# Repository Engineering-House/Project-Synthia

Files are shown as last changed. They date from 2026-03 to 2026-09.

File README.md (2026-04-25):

# Project Synthia
Project Synthia is a digital synthesizer that is designed based upon the Suzuki Omnichord. This repository contains the firmware code for the microcontroller.

## Equipment
The microcontroller used in Project Synthia is a ______.

The programs used are as follows:
- STMCube32MX
- Visual Studio Code
  - STM32CubeIDE for Visual Studio Code (Extension Pack)

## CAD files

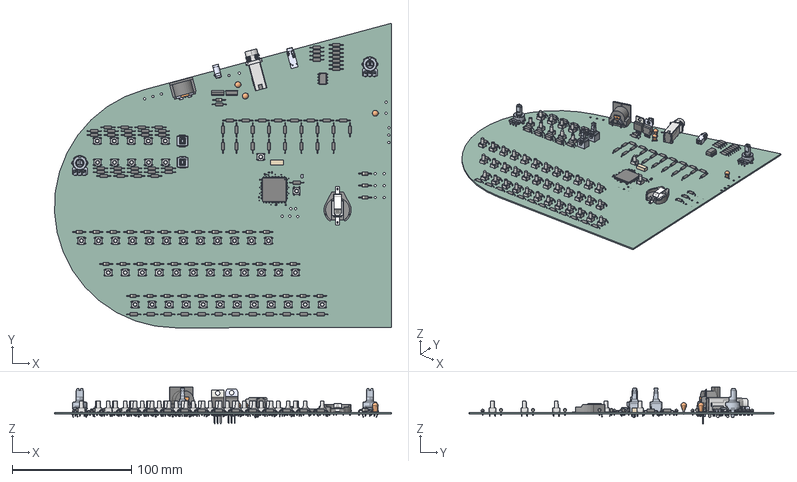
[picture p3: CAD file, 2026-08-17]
synthia/PCB-3D-model-2.step
282.3 x 255.2 x 30.9 mm
STA_CF14_STP x 78
D_DO-41_SOD81_P10.16mm_Horizontal x 40
CAP_CL05_SAM x 15
LQFP144_STM
PVA1EEH31.2NV2 x 2
G-188_MUR x 2
MMBT3904--3DModel-STEP-711646
CAP_CL10_SAM x 2
PJ-007
CCS_CCSTD_0603_L1.75W0.95T0.87B0.35 x 2
CP_Radial_Tantal_D5.0mm_P5.00mm x 3
P120PK x 2
SJ3-35083C-TR
ATS08A-E_CTS
TO-220-3_Vertical
630BT-1
PRT0003-1
630C2-1
630GZ-1
SDS-50J
TLV272IP
LD1117V33
synthia_PCB

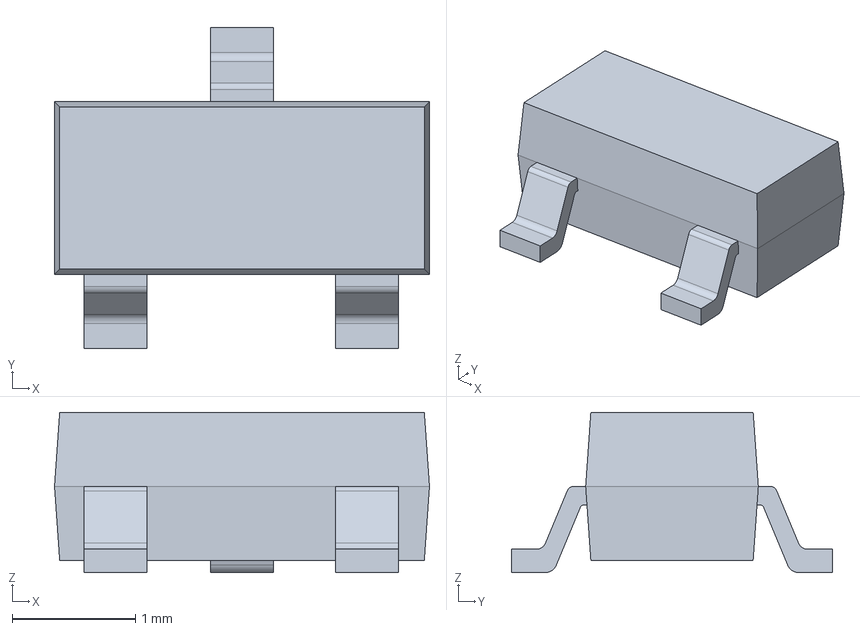
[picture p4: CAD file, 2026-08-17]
synthia/Symbol-and-Footprints/3D_models/sot-23.step
3.04 x 2.60 x 1.30 mm

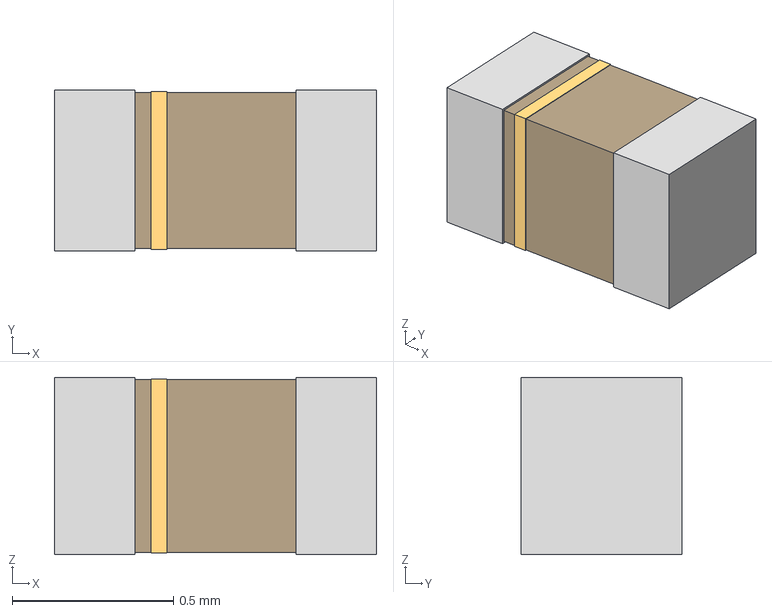
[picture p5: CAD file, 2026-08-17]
synthia/Symbol-and-Footprints/3D_models/CAP_CL05_SAM.step
1.00 x 0.5 x 0.55 mm

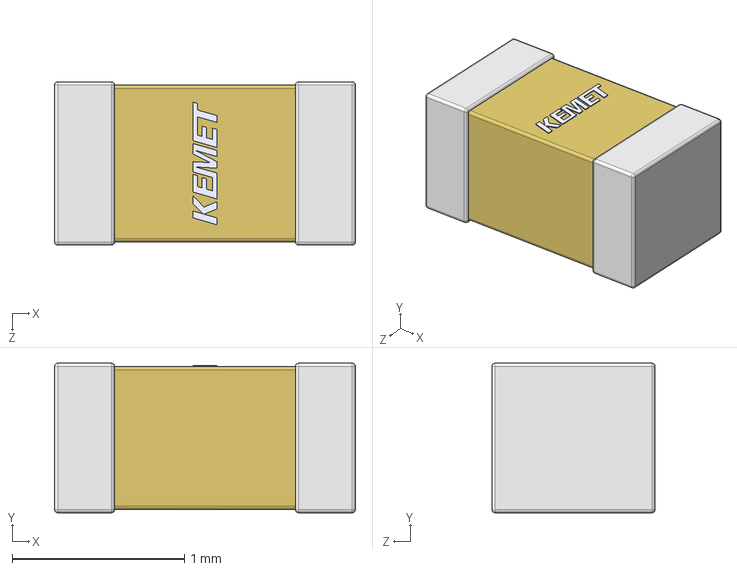
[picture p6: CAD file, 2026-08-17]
synthia/Symbol-and-Footprints/3D_models/CCS_CCSTD_0603_L1.75W0.95T0.87B0.35.step
1.75 x 0.87 x 0.95 mm

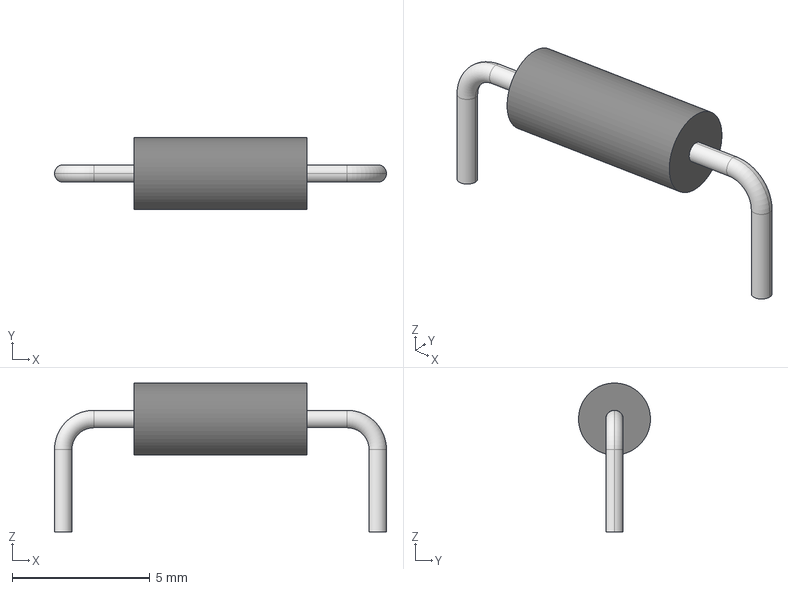
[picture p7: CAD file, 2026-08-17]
synthia/Symbol-and-Footprints/3D_models/STA_CF14_STP.step
12.1 x 2.61 x 5.41 mm

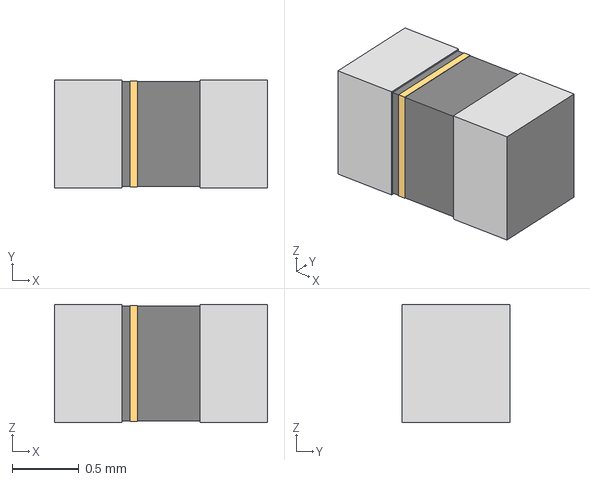
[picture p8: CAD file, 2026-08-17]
synthia/Symbol-and-Footprints/3D_models/G-188_MUR.step
1.60 x 0.812 x 0.889 mm

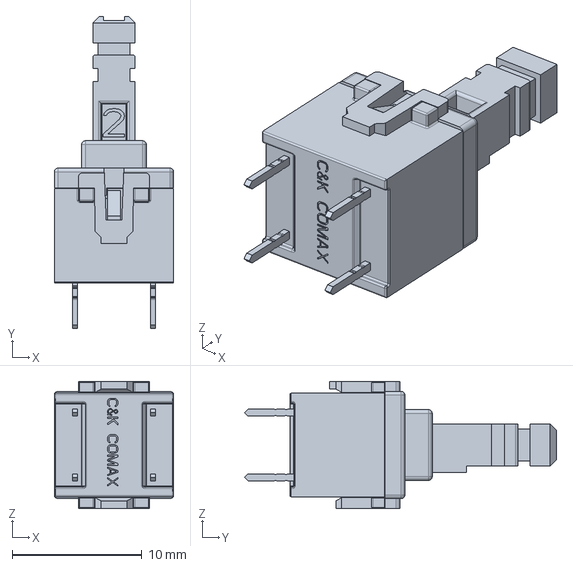
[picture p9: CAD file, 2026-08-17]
synthia/Symbol-and-Footprints/3D_models/PVA1EEH31.2NV2.step
9.20 x 24.0 x 9.80 mm

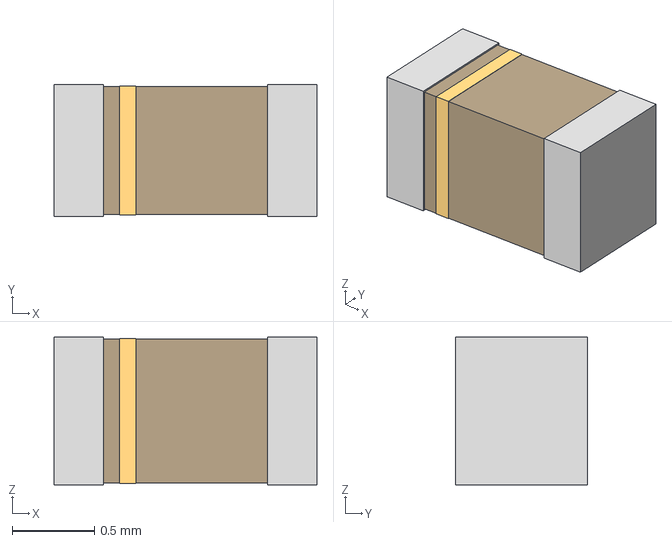
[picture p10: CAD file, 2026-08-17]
synthia/Symbol-and-Footprints/3D_models/CAP_CL10_SAM.step
1.60 x 0.8 x 0.9 mm

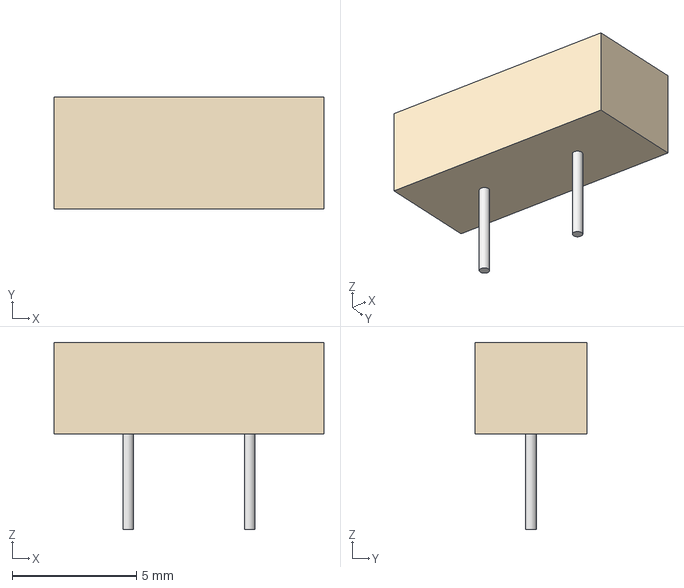
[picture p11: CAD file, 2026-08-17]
synthia/Symbol-and-Footprints/3D_models/ATS08A-E_CTS.step
10.8 x 4.50 x 7.52 mm

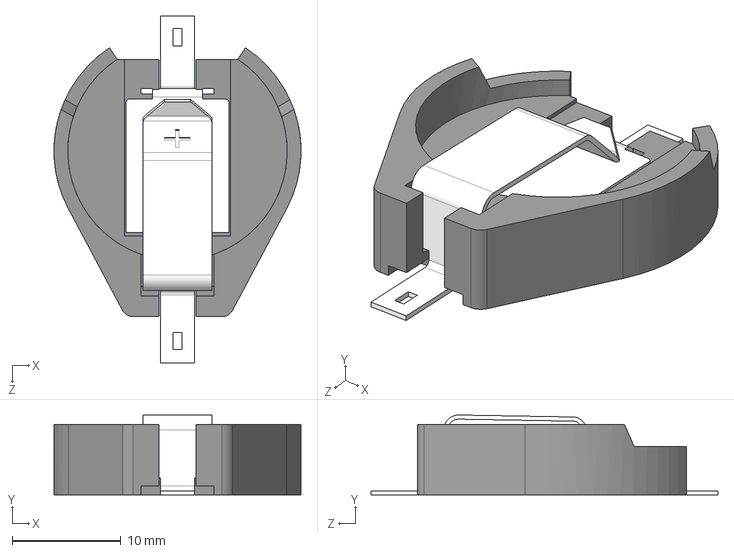
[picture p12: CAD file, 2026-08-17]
synthia/Symbol-and-Footprints/3D_models/1063.step
22.7 x 7.37 x 31.9 mm

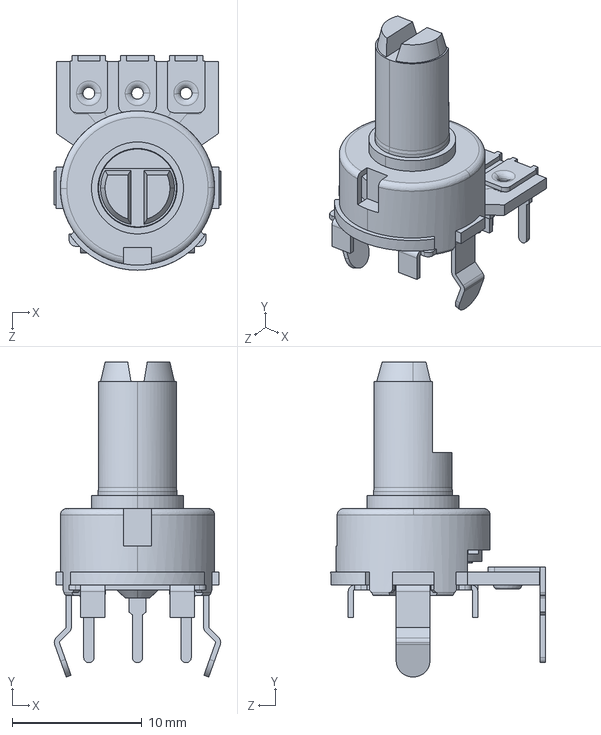
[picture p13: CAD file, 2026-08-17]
synthia/Symbol-and-Footprints/3D_models/P120PK.step
12.8 x 24.3 x 16.6 mm

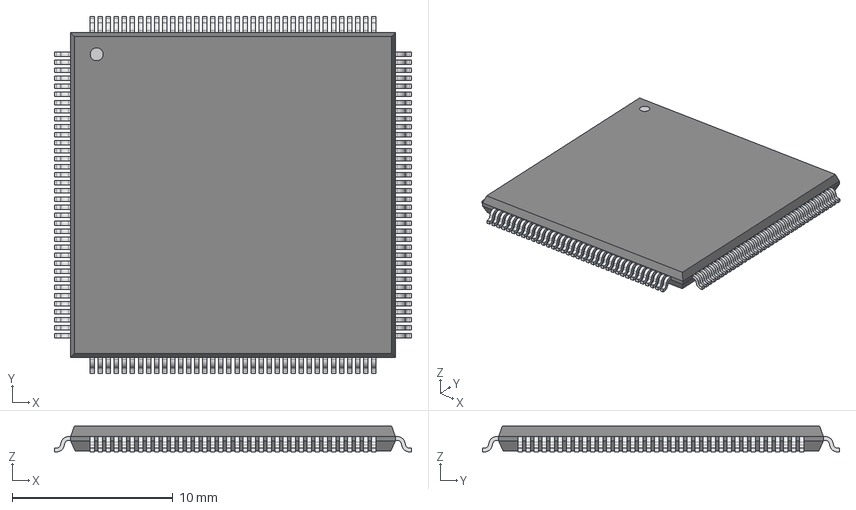
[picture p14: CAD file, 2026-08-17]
synthia/Symbol-and-Footprints/3D_models/LQFP144_STM.step
22.2 x 22.2 x 1.60 mm

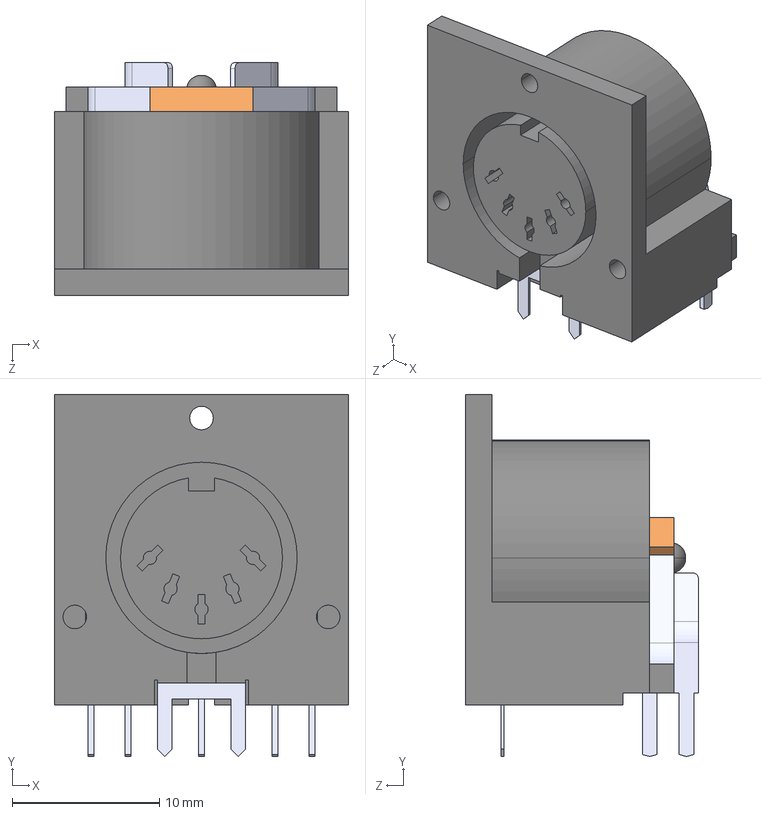
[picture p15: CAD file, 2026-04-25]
synthia/Symbol-and-Footprints/3D_models/SDS-50J.step
20.0 x 24.6 x 15.8 mm

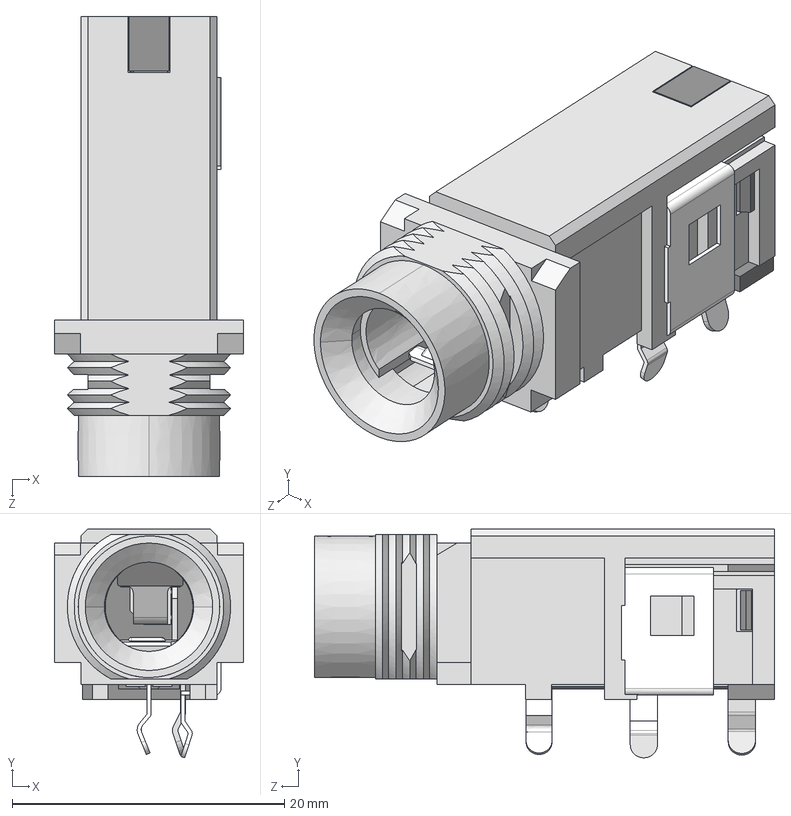
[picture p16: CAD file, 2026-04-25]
synthia/Symbol-and-Footprints/3D_models/MJ-63022B.step
13.9 x 16.8 x 33.8 mm
630BT-1
PRT0003-1
630C2-1
630GZ-1

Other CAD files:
synthia/PCB-3D-model.step
synthia/Symbol-and-Footprints/3D_models/BAS70-05.STEP
synthia/Symbol-and-Footprints/3D_models/SJ3-35083C-TR.step
synthia/Symbol-and-Footprints/3D_models/PJ-007.step
synthia/Symbol-and-Footprints/3D_models/L78M05CV.step
synthia/Symbol-and-Footprints/3D_models/LD1117V33.step
synthia/Symbol-and-Footprints/3D_models/TL1105BF160Q.step
synthia/Symbol-and-Footprints/3D_models/TLV272IP.step

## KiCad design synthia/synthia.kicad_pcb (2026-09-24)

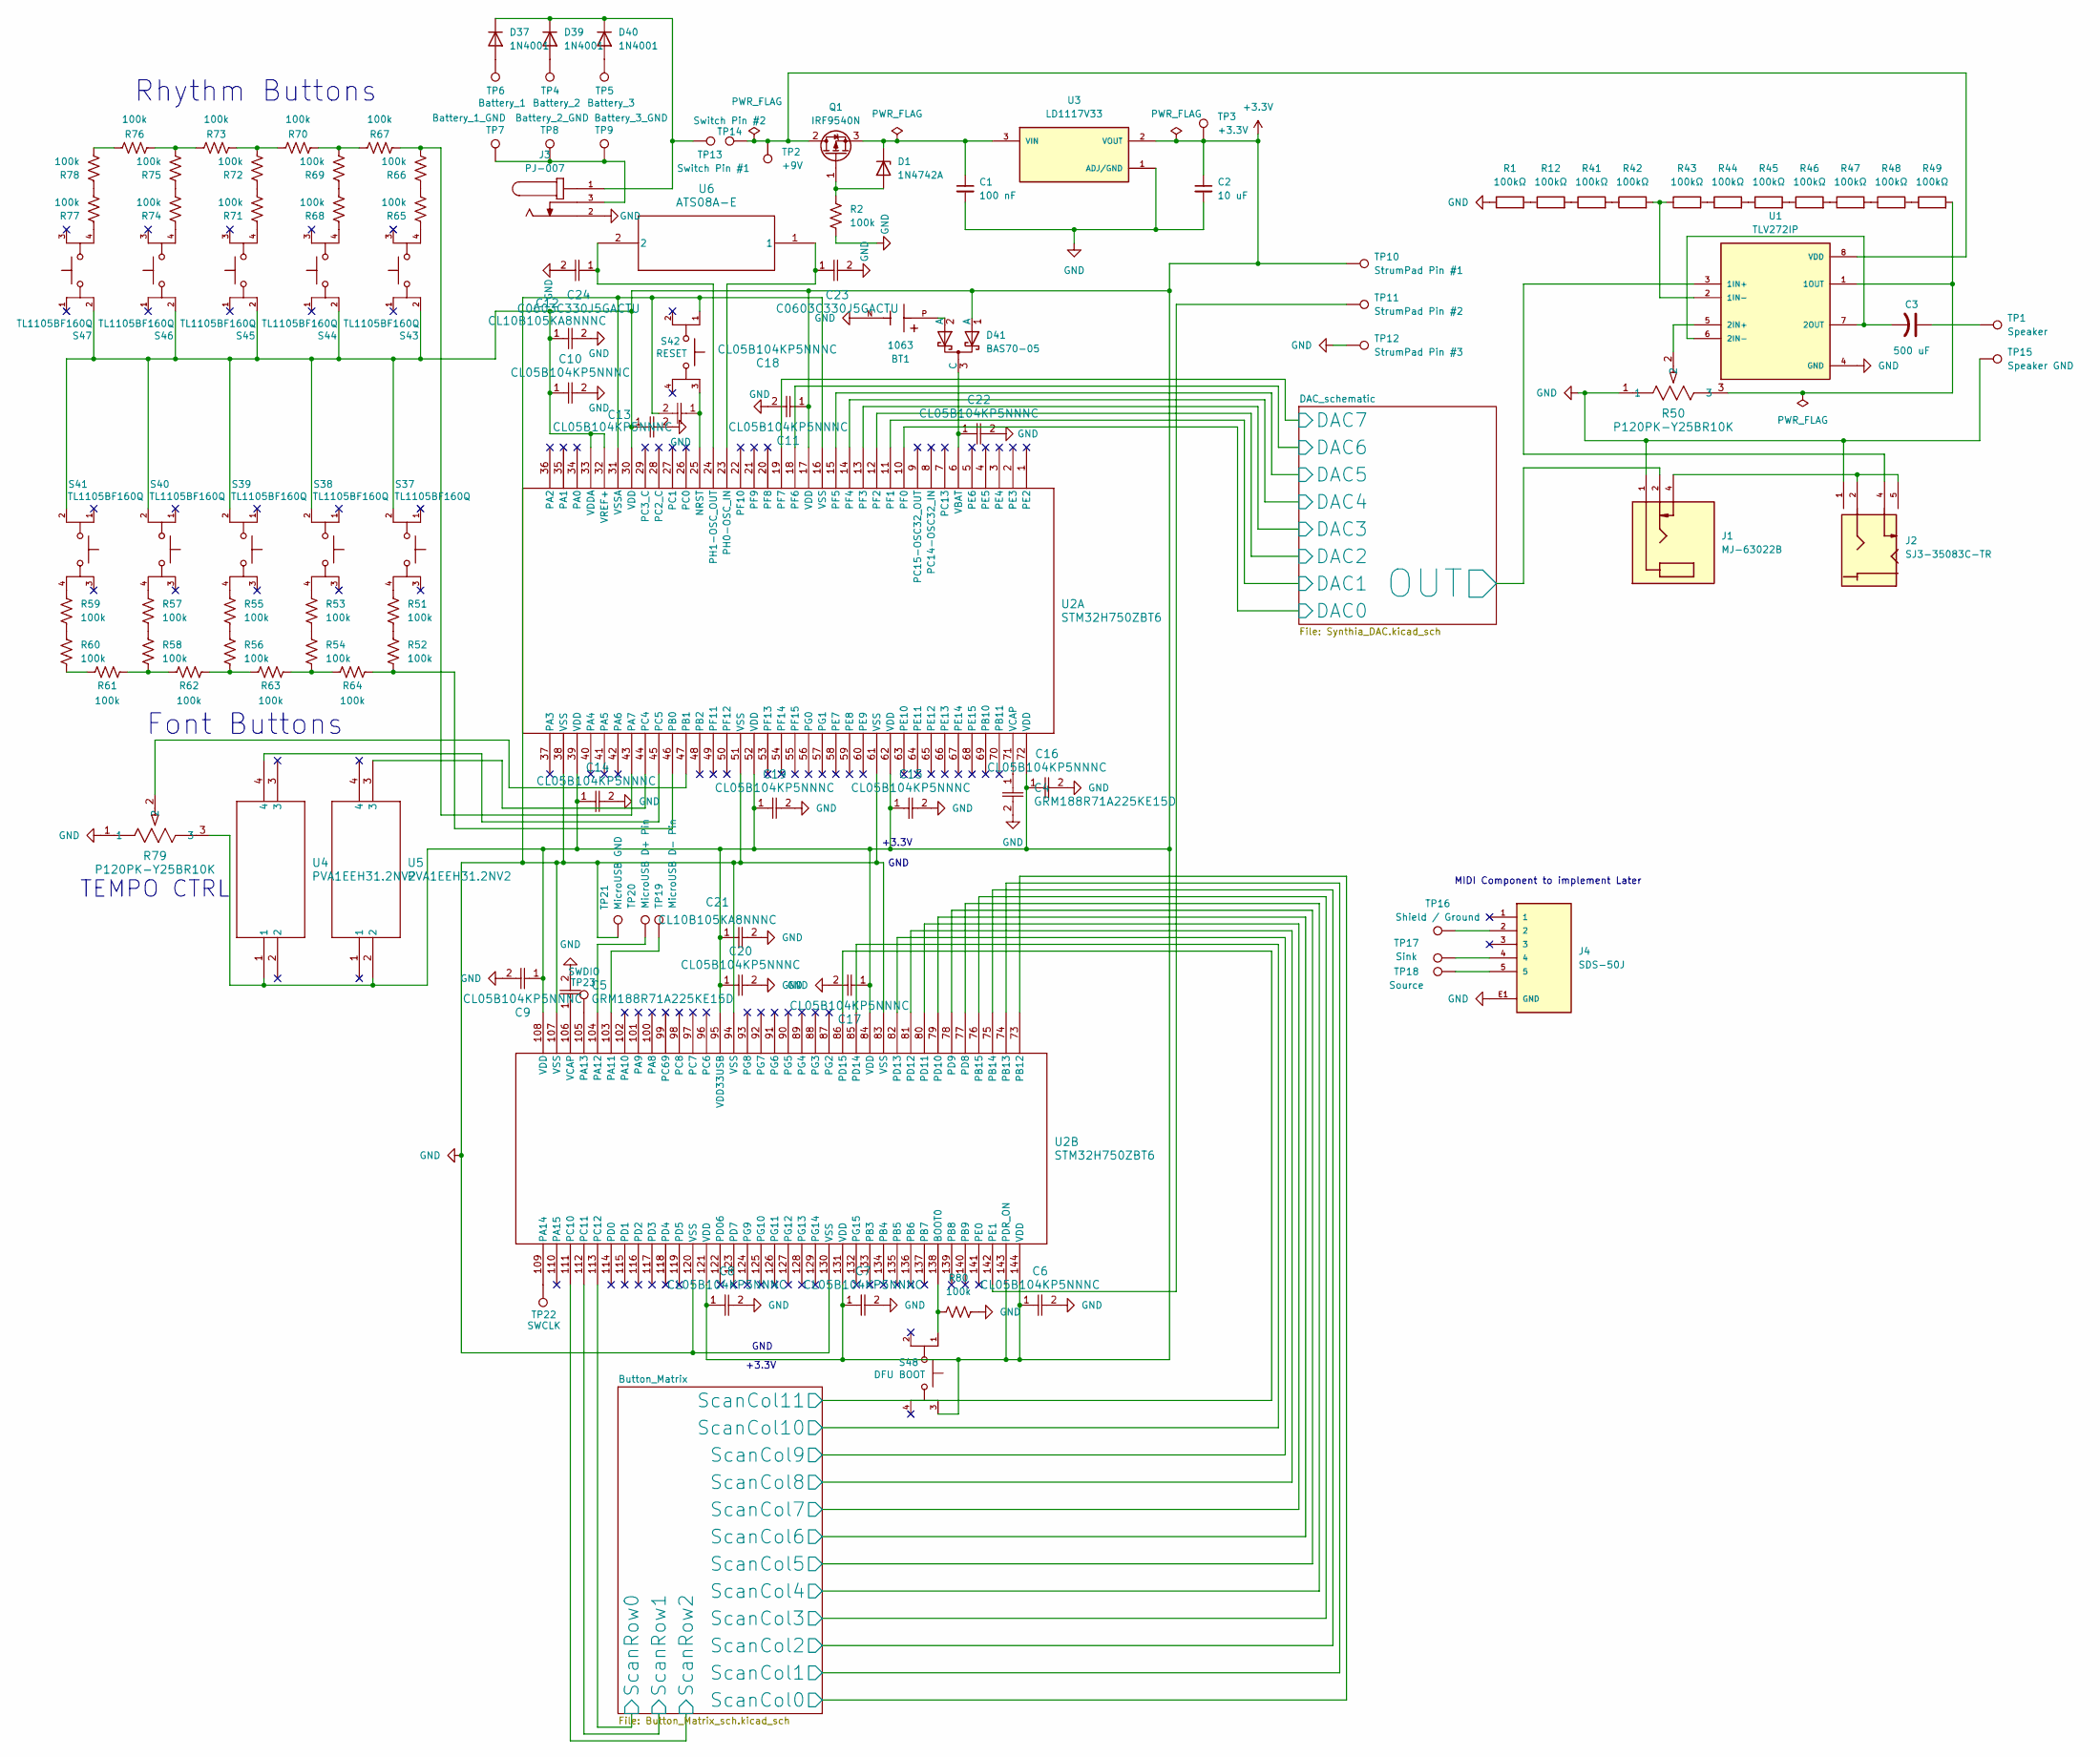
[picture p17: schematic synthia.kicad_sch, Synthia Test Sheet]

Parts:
BT1: 1063; BAT_1063; PARTREV F
C1: 100 nF; CP_Radial_Tantal_D5.0mm_P5.00mm
C2: 10 uF; CP_Radial_Tantal_D5.0mm_P5.00mm
C3: 500 uF; CP_Radial_Tantal_D5.0mm_P5.00mm
C4, C5: GRM188R71A225KE15D; G-188_MUR
C6, C7, C8, C9, C10, C11, C13, C14, C15, C16, C17, C18, C19, C20, C22: CL05B104KP5NNNC; CAP_CL05_SAM-L
C12, C21: CL10B105KA8NNNC; CAP_CL10_SAM-L
C23, C24: C0603C330J5GACTU; CAPC17595_87N_KEM-L
D1: 1N4742A; D_DO-41_SOD81_P10.16mm_Horizontal
D37, D39, D40: 1N4001; D_DO-41_SOD81_P10.16mm_Horizontal
D41: BAS70-05; P200_SOT-23
J1: MJ-63022B; CUI_MJ-63022B; PARTREV 1.0
J2: SJ3-35083C-TR; SAMESKY_SJ3-35083C-TR; PARTREV 1.01
J3: PJ-007; SAMESKY_PJ-007; PARTREV 1.07
J4: SDS-50J; CUI_SDS-50J; PARTREV 1.06/02-13-2020
Q1: IRF9540N; TO-220-3_Vertical
R1, R12, R41, R42, R43, R44, R45, R46, R47, R48, R49: 100kΩ; STA_CF14_STP
R2, R51, R52, R53, R54, R55, R56, R57, R58, R59, R60, R61, R62, R63, R64, R65, R66, R67, R68, R69, R70, R71, R72, R73, R74, R75, R76, R77, R78, R80: 100k; STA_CF14_STP
R50, R79: P120PK-Y25BR10K; POT_P120PK-x25_TTE
S37, S38, S39, S40, S41, S43, S44, S45, S46, S47: TL1105BF160Q; SW_TL1105BF160Q; PARTREV A
S42: RESET; SW_TL1105BF160Q; PARTREV A
S48: DFU BOOT; SW_TL1105BF160Q; PARTREV A
TP1: Speaker; TestPoint_Plated_Hole_D2.0mm
TP2: +9V; TestPoint_Pad_2.0x2.0mm
TP3: +3.3V; TestPoint_Pad_2.0x2.0mm
TP4: Battery_2; TestPoint_Plated_Hole_D2.0mm
TP5: Battery_3; TestPoint_Plated_Hole_D2.0mm
TP6: Battery_1; TestPoint_Plated_Hole_D2.0mm
TP7: Battery_1_GND; TestPoint_Plated_Hole_D2.0mm
TP8: Battery_2_GND; TestPoint_Plated_Hole_D2.0mm
TP9: Battery_3_GND; TestPoint_Plated_Hole_D2.0mm
TP10: StrumPad Pin #1; TestPoint_Plated_Hole_D2.0mm
TP11: StrumPad Pin #2; TestPoint_Plated_Hole_D2.0mm
TP12: StrumPad Pin #3; TestPoint_Plated_Hole_D2.0mm
TP13: Switch Pin #1; TestPoint_Plated_Hole_D2.0mm
TP14: Switch Pin #2; TestPoint_Plated_Hole_D2.0mm
TP15: Speaker GND; TestPoint_Plated_Hole_D2.0mm
TP16: Shield / Ground; TestPoint_Plated_Hole_D2.0mm
TP17: Sink; TestPoint_Plated_Hole_D2.0mm
TP18: Source; TestPoint_Plated_Hole_D2.0mm
TP19: MicroUSB D- Pin; TestPoint_Plated_Hole_D2.0mm
TP20: MicroUSB D+ Pin; TestPoint_Plated_Hole_D2.0mm
TP21: MicroUSB GND; TestPoint_Plated_Hole_D2.0mm
TP22: SWCLK; TestPoint_Plated_Hole_D2.0mm
TP23: SWDIO; TestPoint_Plated_Hole_D2.0mm
U1: TLV272IP; DIP794W45P254L959H508Q8; PARTREV E
U2: STM32H750ZBT6; LQFP144_STM
U3: LD1117V33; TO255P1020X450X1968-3; PARTREV 37
U4, U5: PVA1EEH31.2NV2; SWITCH_H31.2NV2
U6: ATS08A-E; ATS08A-E_CTS

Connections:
+3.3V: C2.1, C6.1, C7.1, C8.1, C9.1, C10.1, C11.1, C12.1, C13.1, C14.1, C15.1, C16.1, C17.1, C19.1, C20.1, C21.1, D41.1 (A), R79.3, S37.2, S38.2, S39.2, S40.2, S41.2, S43.2, S44.2, S45.2, S46.2, S47.2, S48.3, TP3.1 (1_1), TP10.1 (1_1), U2.17 (VDD), U2.30 (VDD), U2.32 (VREF+), U2.33 (VDDA), U2.39 (VDD), U2.52 (VDD), U2.62 (VDD), U2.72 (VDD), U2.84 (VDD), U2.95 (VDD33USB), U2.108 (VDD), U2.121 (VDD), U2.131 (VDD), U2.143 (PDR_ON), U2.144 (VDD), U3.2 (VOUT), U4.1, U5.2
/Button_Matrix/ScanCol0: U2.73 (PB12); also elsewhere on the board
/Button_Matrix/ScanCol1: U2.74 (PB13); also elsewhere on the board
/Button_Matrix/ScanCol2: U2.75 (PB14); also elsewhere on the board
/Button_Matrix/ScanCol3: U2.76 (PB15); also elsewhere on the board
/Button_Matrix/ScanCol4: U2.77 (PD8); also elsewhere on the board
/Button_Matrix/ScanCol5: U2.78 (PD9); also elsewhere on the board
/Button_Matrix/ScanCol6: U2.79 (PD10); also elsewhere on the board
/Button_Matrix/ScanCol7: U2.80 (PD11); also elsewhere on the board
/Button_Matrix/ScanCol8: U2.81 (PD12); also elsewhere on the board
/Button_Matrix/ScanCol9: U2.82 (PD13); also elsewhere on the board
/Button_Matrix/ScanCol10: U2.85 (PD14); also elsewhere on the board
/Button_Matrix/ScanCol11: U2.86 (PD15); also elsewhere on the board
/Button_Matrix/ScanRow0: U2.113 (PC12); also elsewhere on the board
/Button_Matrix/ScanRow1: U2.112 (PC11); also elsewhere on the board
/Button_Matrix/ScanRow2: U2.111 (PC10); also elsewhere on the board
/DAC_schematic/DAC0: U2.10 (PF0); also elsewhere on the board
/DAC_schematic/DAC1: U2.11 (PF1); also elsewhere on the board
/DAC_schematic/DAC2: U2.12 (PF2); also elsewhere on the board
/DAC_schematic/DAC3: U2.13 (PF3); also elsewhere on the board
/DAC_schematic/DAC4: U2.14 (PF4); also elsewhere on the board
/DAC_schematic/DAC5: U2.15 (PF5); also elsewhere on the board
/DAC_schematic/DAC6: U2.18 (PF6); also elsewhere on the board
/DAC_schematic/DAC7: U2.19 (PF7); also elsewhere on the board
/DAC_schematic/OUT: J1.2; also elsewhere on the board
GND: BT1.N, C1.2, C2.2, C4.2, C5.2, C6.2, C7.2, C8.2, C9.2, C10.2, C11.2, C12.2, C13.2, C14.2, C15.2, C16.2, C17.2, C18.2, C19.2, C20.2, C21.2, C22.2, C23.2, C24.2, J1.1, J2.1, J3.2, J4.E1 (GND), J4.E2 (GND), R1.1, R2.2, R50.1, R79.1, R80.2, S42.1, TP12.1 (1_1), TP15.1 (1_1), TP21.1 (1_1), U1.4 (GND), U2.16 (VSS), U2.31 (VSSA), U2.38 (VSS), U2.51 (VSS), U2.61 (VSS), U2.83 (VSS), U2.94 (VSS), U2.107 (VSS), U2.120 (VSS), U2.130 (VSS), U3.1 (ADJ/GND); also elsewhere on the board
unnamed: BT1.P, D41.2 (A)
unnamed: C3.1, TP1.1 (1_1)
unnamed: D1.2 (A), Q1.1 (G), R2.1
unnamed: C1.1, D1.1 (K), Q1.3 (S), U3.3 (VIN)
unnamed: D37.2 (A), TP6.1 (1_1)
unnamed: D37.1 (K), D39.1 (K), D40.1 (K), J3.1, TP13.1 (1_1)
unnamed: D39.2 (A), TP4.1 (1_1)
unnamed: D40.2 (A), TP5.1 (1_1)
unnamed: C22.1, D41.3 (C), U2.6 (VBAT)
unnamed: J1.4, J2.2, J2.5
unnamed: J3.3, TP7.1 (1_1), TP8.1 (1_1), TP9.1 (1_1)
unnamed: J4.2, TP16.1 (1_1)
unnamed: J4.4, TP17.1 (1_1)
unnamed: J4.5, TP18.1 (1_1)
unnamed: Q1.2 (D), TP2.1 (1_1), TP14.1 (1_1), U1.8 (VDD)
unnamed: R1.2, R12.1
unnamed: R12.2, R41.1
unnamed: R41.2, R42.1
unnamed: R43.2, R44.1
unnamed: R44.2, R45.1
unnamed: R45.2, R46.1
unnamed: R46.2, R47.1
unnamed: R47.2, R48.1
unnamed: R48.2, R49.1
unnamed: R51.1, S37.4
unnamed: R51.2, R52.1
unnamed: R53.1, S38.4
unnamed: R53.2, R54.1
unnamed: R54.2, R63.2, R64.1
unnamed: R55.1, S39.4
unnamed: R55.2, R56.1
unnamed: R56.2, R62.2, R63.1
unnamed: R57.1, S40.4
unnamed: R57.2, R58.1
unnamed: R58.2, R61.2, R62.1
unnamed: R59.1, S41.4
unnamed: R59.2, R60.1
unnamed: R60.2, R61.1
unnamed: R65.1, S43.4
unnamed: R65.2, R66.1
unnamed: R67.2, R69.2, R70.1
unnamed: R68.1, S44.4
unnamed: R68.2, R69.1
unnamed: R70.2, R72.2, R73.1
unnamed: R71.1, S45.4
unnamed: R71.2, R72.1
unnamed: R73.2, R75.2, R76.1
unnamed: R74.1, S46.4
unnamed: R74.2, R75.1
unnamed: R76.2, R78.2
unnamed: R77.1, S47.4
unnamed: R77.2, R78.1
unnamed: J2.4, U1.3 (1IN+)
unnamed: R42.2, R43.1, U1.2 (1IN-)
unnamed: R49.2, R50.3, U1.1 (1OUT)
unnamed: R50.2, U1.5 (2IN+)
unnamed: C3.2, U1.6 (2IN-), U1.7 (2OUT)
unnamed: C18.1, S42.3, U2.25 (NRST)
unnamed: R66.2, R67.1, U2.43 (PA7)
unnamed: R52.2, R64.2, U2.46 (PB0)
unnamed: R79.2, U2.47 (PB1)
unnamed: U2.44 (PC4), U5.3
unnamed: U2.45 (PC5), U4.4
unnamed: C23.1, U2.23 (PH0-OSC_IN), U6.1
unnamed: C24.1, U2.24 (PH1-OSC_OUT), U6.2
unnamed: C4.1, U2.71 (VCAP)
unnamed: R80.1, S48.1, U2.138 (BOOT0)
unnamed: TP19.1 (1_1), U2.103 (PA11)
unnamed: TP20.1 (1_1), U2.104 (PA12)
unnamed: TP23.1 (1_1), U2.105 (PA13)
unnamed: TP22.1 (1_1), U2.109 (PA14)
unnamed: TP11.1 (1_1), U2.142 (PE1)
unnamed: C5.1, U2.106 (VCAP)

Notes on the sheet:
+3.3V
GND
TEMPO CTRL
MIDI Component to implement Later
Font Buttons
Rhythm Buttons

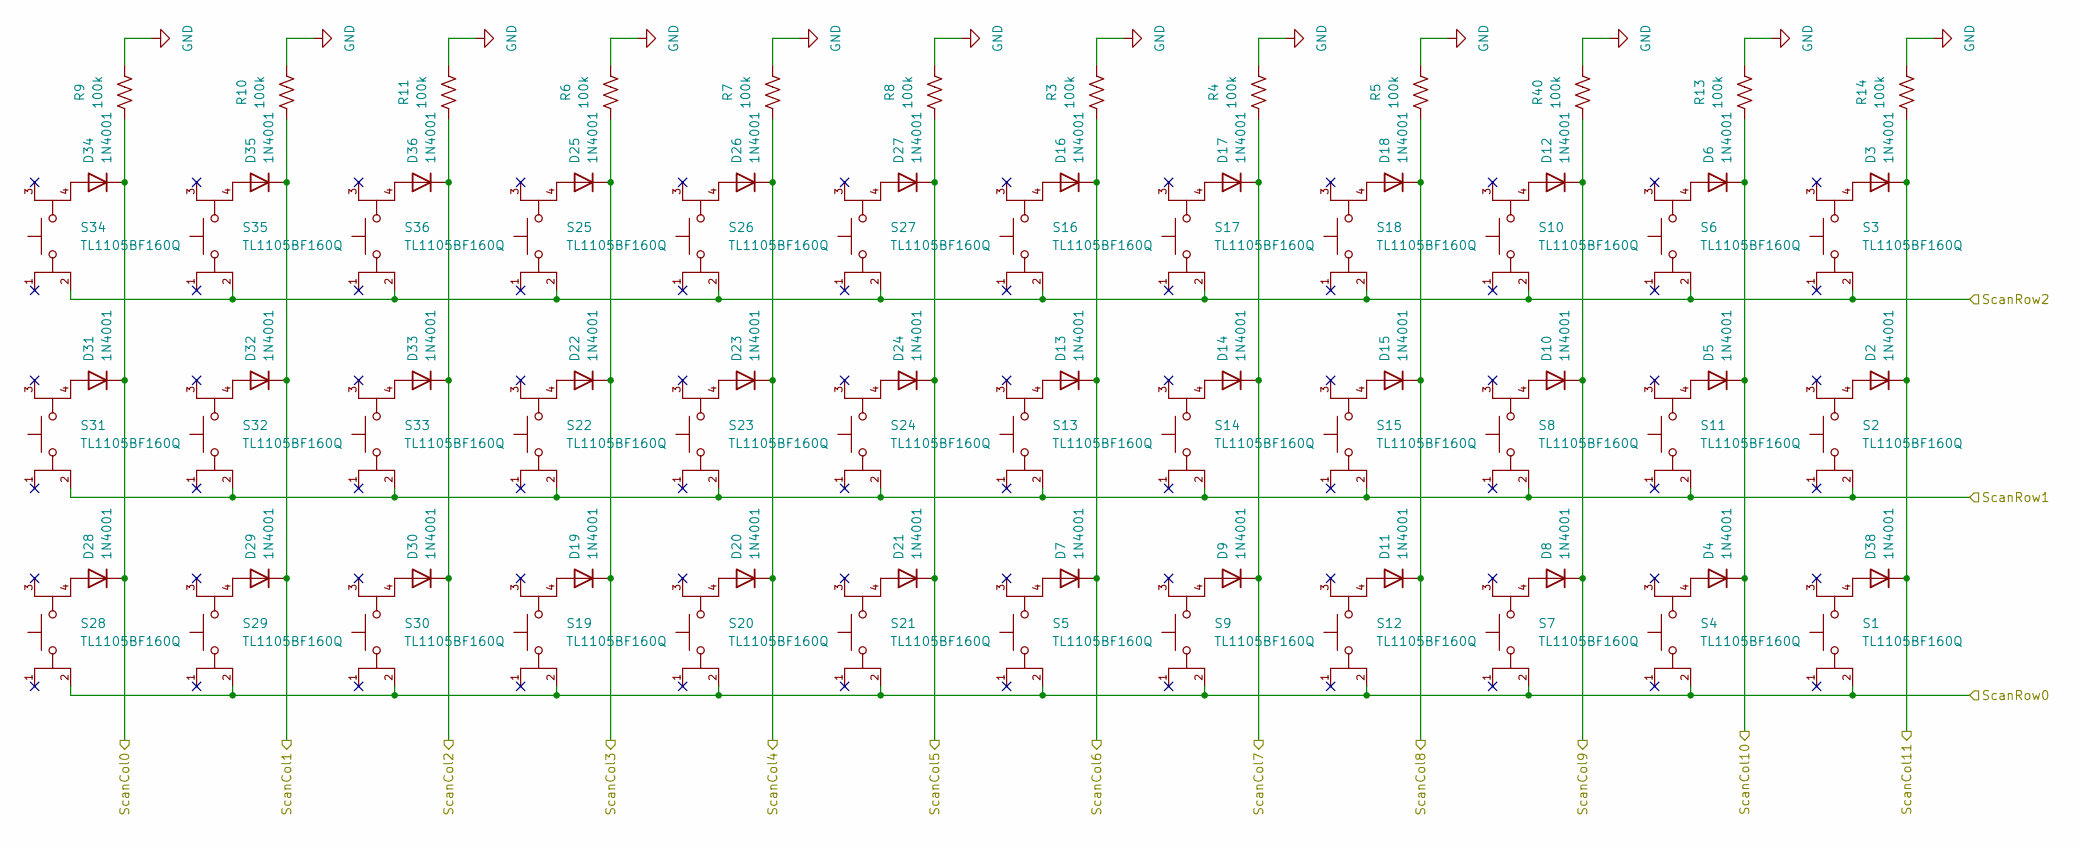
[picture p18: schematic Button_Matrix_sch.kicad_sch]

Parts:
D2, D3, D4, D5, D6, D7, D8, D9, D10, D11, D12, D13, D14, D15, D16, D17, D18, D19, D20, D21, D22, D23, D24, D25, D26, D27, D28, D29, D30, D31, D32, D33, D34, D35, D36, D38: 1N4001; D_DO-41_SOD81_P10.16mm_Horizontal
R3, R4, R5, R6, R7, R8, R9, R10, R11, R13, R14, R40: 100k; STA_CF14_STP
S1, S2, S3, S4, S5, S6, S7, S8, S9, S10, S11, S12, S13, S14, S15, S16, S17, S18, S19, S20, S21, S22, S23, S24, S25, S26, S27, S28, S29, S30, S31, S32, S33, S34, S35, S36: TL1105BF160Q; SW_TL1105BF160Q; PARTREV A

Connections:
/Button_Matrix/ScanCol0: D28.1 (K), D31.1 (K), D34.1 (K), R9.1; also elsewhere on the board
/Button_Matrix/ScanCol1: D29.1 (K), D32.1 (K), D35.1 (K), R10.1; also elsewhere on the board
/Button_Matrix/ScanCol2: D30.1 (K), D33.1 (K), D36.1 (K), R11.1; also elsewhere on the board
/Button_Matrix/ScanCol3: D19.1 (K), D22.1 (K), D25.1 (K), R6.1; also elsewhere on the board
/Button_Matrix/ScanCol4: D20.1 (K), D23.1 (K), D26.1 (K), R7.1; also elsewhere on the board
/Button_Matrix/ScanCol5: D21.1 (K), D24.1 (K), D27.1 (K), R8.1; also elsewhere on the board
/Button_Matrix/ScanCol6: D7.1 (K), D13.1 (K), D16.1 (K), R3.1; also elsewhere on the board
/Button_Matrix/ScanCol7: D9.1 (K), D14.1 (K), D17.1 (K), R4.1; also elsewhere on the board
/Button_Matrix/ScanCol8: D11.1 (K), D15.1 (K), D18.1 (K), R5.1; also elsewhere on the board
/Button_Matrix/ScanCol9: D8.1 (K), D10.1 (K), D12.1 (K), R40.1; also elsewhere on the board
/Button_Matrix/ScanCol10: D4.1 (K), D5.1 (K), D6.1 (K), R13.1; also elsewhere on the board
/Button_Matrix/ScanCol11: D2.1 (K), D3.1 (K), D38.1 (K), R14.1; also elsewhere on the board
/Button_Matrix/ScanRow0: S1.2, S4.2, S5.2, S7.2, S9.2, S12.2, S19.2, S20.2, S21.2, S28.2, S29.2, S30.2; also elsewhere on the board
/Button_Matrix/ScanRow1: S2.2, S8.2, S11.2, S13.2, S14.2, S15.2, S22.2, S23.2, S24.2, S31.2, S32.2, S33.2; also elsewhere on the board
/Button_Matrix/ScanRow2: S3.2, S6.2, S10.2, S16.2, S17.2, S18.2, S25.2, S26.2, S27.2, S34.2, S35.2, S36.2; also elsewhere on the board
GND: R3.2, R4.2, R5.2, R6.2, R7.2, R8.2, R9.2, R10.2, R11.2, R13.2, R14.2, R40.2; also elsewhere on the board
unnamed: D2.2 (A), S2.4
unnamed: D3.2 (A), S3.4
unnamed: D4.2 (A), S4.4
unnamed: D5.2 (A), S11.4
unnamed: D6.2 (A), S6.4
unnamed: D7.2 (A), S5.4
unnamed: D8.2 (A), S7.4
unnamed: D9.2 (A), S9.4
unnamed: D10.2 (A), S8.4
unnamed: D11.2 (A), S12.4
unnamed: D12.2 (A), S10.4
unnamed: D13.2 (A), S13.4
unnamed: D14.2 (A), S14.4
unnamed: D15.2 (A), S15.4
unnamed: D16.2 (A), S16.4
unnamed: D17.2 (A), S17.4
unnamed: D18.2 (A), S18.4
unnamed: D19.2 (A), S19.4
unnamed: D20.2 (A), S20.4
unnamed: D21.2 (A), S21.4
unnamed: D22.2 (A), S22.4
unnamed: D23.2 (A), S23.4
unnamed: D24.2 (A), S24.4
unnamed: D25.2 (A), S25.4
unnamed: D26.2 (A), S26.4
unnamed: D27.2 (A), S27.4
unnamed: D28.2 (A), S28.4
unnamed: D29.2 (A), S29.4
unnamed: D30.2 (A), S30.4
unnamed: D31.2 (A), S31.4
unnamed: D32.2 (A), S32.4
unnamed: D33.2 (A), S33.4
unnamed: D34.2 (A), S34.4
unnamed: D35.2 (A), S35.4
unnamed: D36.2 (A), S36.4
unnamed: D38.2 (A), S1.4

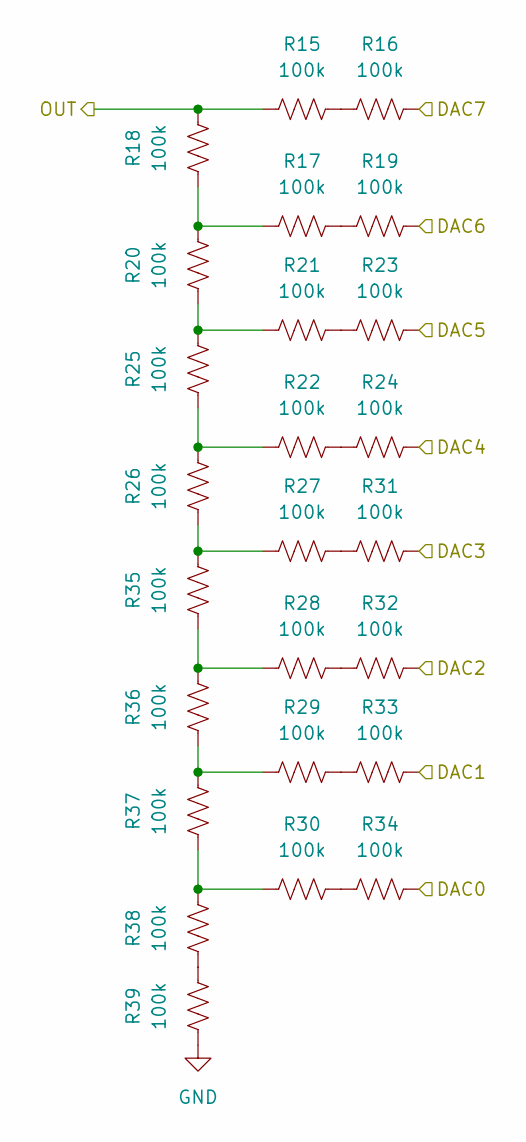
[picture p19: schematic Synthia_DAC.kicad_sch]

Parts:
R15, R16, R17, R18, R19, R20, R21, R22, R23, R24, R25, R26, R27, R28, R29, R30, R31, R32, R33, R34, R35, R36, R37, R38, R39: 100k; STA_CF14_STP

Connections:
/DAC_schematic/DAC0: R34.2; also elsewhere on the board
/DAC_schematic/DAC1: R33.2; also elsewhere on the board
/DAC_schematic/DAC2: R32.2; also elsewhere on the board
/DAC_schematic/DAC3: R31.2; also elsewhere on the board
/DAC_schematic/DAC4: R24.2; also elsewhere on the board
/DAC_schematic/DAC5: R23.2; also elsewhere on the board
/DAC_schematic/DAC6: R19.2; also elsewhere on the board
/DAC_schematic/DAC7: R16.2; also elsewhere on the board
/DAC_schematic/OUT: R15.1, R18.2; also elsewhere on the board
GND: R39.1; also elsewhere on the board
unnamed: R15.2, R16.1
unnamed: R17.1, R18.1, R20.2
unnamed: R17.2, R19.1
unnamed: R20.1, R21.1, R25.2
unnamed: R21.2, R23.1
unnamed: R22.1, R25.1, R26.2
unnamed: R22.2, R24.1
unnamed: R26.1, R27.1, R35.2
unnamed: R27.2, R31.1
unnamed: R28.1, R35.1, R36.2
unnamed: R28.2, R32.1
unnamed: R29.1, R36.1, R37.2
unnamed: R29.2, R33.1
unnamed: R30.1, R37.1, R38.2
unnamed: R30.2, R34.1
unnamed: R38.1, R39.2

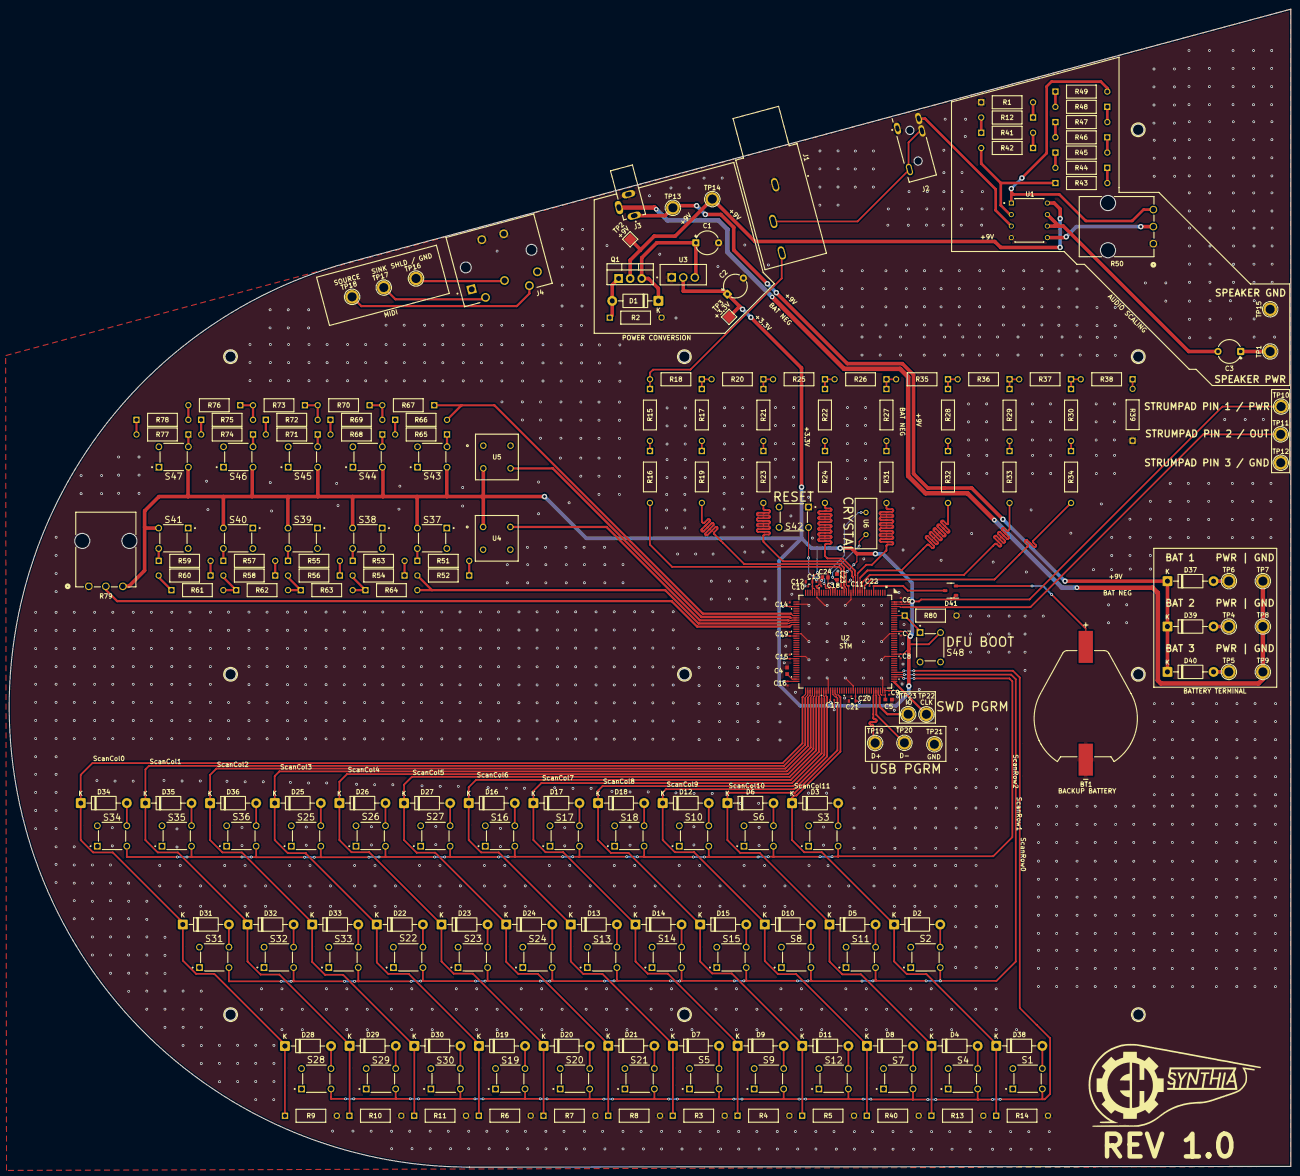
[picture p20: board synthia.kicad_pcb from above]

Board: 2 copper layers, 282.4 x 255.2 mm, 229 parts (0 on the bottom side), 151 nets.

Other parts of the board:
LOGO: LOGO

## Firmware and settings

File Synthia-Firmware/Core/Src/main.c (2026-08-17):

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
/* Includes ------------------------------------------------------------------*/
#include "main.h"

/* USER CODE BEGIN Includes */
#include "audio_gpio.h"

extern uint8_t supersaw[];
extern uint32_t supersaw_length;
/* USER CODE END Includes */


COM_InitTypeDef BspCOMInit;

TIM_HandleTypeDef htim1;
TIM_HandleTypeDef htim2;

/* USER CODE BEGIN PV */
volatile uint32_t audio_index = 0;
/* USER CODE END PV */

void SystemClock_Config(void);
static void MX_GPIO_Init(void);
static void MX_TIM1_Init(void);
static void MX_TIM2_Init(void);
/**
  * @brief  The application entry point.
  * @retval int
  */
int main(void)
{

  /* MCU Configuration--------------------------------------------------------*/

  /* Reset of all peripherals, Initializes the Flash interface and the Systick. */
  HAL_Init();

  /* Configure the system clock */
  SystemClock_Config();

  /* Initialize all configured peripherals */
  MX_GPIO_Init();
  MX_TIM1_Init();
  MX_TIM2_Init();
  /* USER CODE BEGIN 2 */
  AudioGPIO_Init();
  /* USER CODE END 2 */

  /* Initialize leds */
  BSP_LED_Init(LED_GREEN);

  /* Initialize COM1 port (115200, 8 bits (7-bit data + 1 stop bit), no parity */
  BspCOMInit.BaudRate   = 115200;
  BspCOMInit.WordLength = COM_WORDLENGTH_8B;
  BspCOMInit.StopBits   = COM_STOPBITS_1;
  BspCOMInit.Parity     = COM_PARITY_NONE;
  BspCOMInit.HwFlowCtl  = COM_HWCONTROL_NONE;
  if (BSP_COM_Init(COM1, &BspCOMInit) != BSP_ERROR_NONE)
  {
    Error_Handler();
  }

  /* USER CODE BEGIN BSP */

  /* -- Sample board code to send message over COM1 port ---- */
  printf("Welcome to STM32 world !\n\r");

  /* -- Sample board code to switch on leds ---- */
  BSP_LED_On(LED_GREEN);

  /* USER CODE END BSP */

  /* Infinite loop */
  /* USER CODE BEGIN WHILE */
  while (1)
  {

/* -- Sample board code to toggle leds ---- */
       BSP_LED_Toggle(LED_GREEN);

    /* USER CODE END WHILE */

    /* USER CODE BEGIN 3 */
  }
  /* USER CODE END 3 */
}

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
/* USER CODE BEGIN 4 */
void HAL_TIM_PeriodElapsedCallback(TIM_HandleTypeDef *htim)
{
    if (htim->Instance == TIM1)
    {
        AudioGPIO_Output(supersaw[audio_index++]);

        if (audio_index >= supersaw_length)
            audio_index = 0; // loop
    }
}
/* USER CODE END 4 */

/* USER CODE BEGIN Header */
/**
  ******************************************************************************
  * @file           : main.c
  * @brief          : Main program body
  ******************************************************************************
  * @attention
  *
  * Copyright (c) 2026 STMicroelectronics.
  * All rights reserved.
  *
  * This software is licensed under terms that can be found in the LICENSE file
  * in the root directory of this software component.
  * If no LICENSE file comes with this software, it is provided AS-IS.
  *
  ******************************************************************************
  */
/* USER CODE END Header */

/**
  * @}
  */

/**
  * @}
  */

/**
  * @brief  This function is executed in case of error occurrence.
  * @retval None
  */
void Error_Handler(void)
{
  /* USER CODE BEGIN Error_Handler_Debug */
  /* User can add his own implementation to report the HAL error return state */
  __disable_irq();
  while (1)
  {
  }
  /* USER CODE END Error_Handler_Debug */
}
#ifdef USE_FULL_ASSERT
/**
  * @brief  Reports the name of the source file and the source line number
  *         where the assert_param error has occurred.
  * @param  file: pointer to the source file name
  * @param  line: assert_param error line source number
  * @retval None
  */
void assert_failed(uint8_t *file, uint32_t line)
{
  /* USER CODE BEGIN 6 */
  /* User can add his own implementation to report the file name and line number,
     ex: printf("Wrong parameters value: file %s on line %d\r\n", file, line) */
  /* USER CODE END 6 */
}
#endif /* USE_FULL_ASSERT */

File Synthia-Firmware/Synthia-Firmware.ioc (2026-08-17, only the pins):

Mcu.UserName=STM32G431KBTx
PA0.Signal=GPIO_Output
PA1.Signal=GPIO_Output
PA13.GPIO_Label=T_SWDIO
PA13.Signal=SYS_JTMS-SWDIO
PA14.GPIO_Label=T_SWCLK
PA14.Signal=SYS_JTCK-SWCLK
PA2.Signal=USART2_TX
PA3.Signal=USART2_RX
PA4.Signal=GPIO_Output
PA5.Signal=GPIO_Output
PA6.Signal=GPIO_Output
PA7.Signal=GPIO_Output
PA8.Signal=GPIO_Output
PA9.Signal=GPIO_Output
PB0.Signal=GPIO_Output
PB3.GPIO_Label=T_SWO
PB3.Signal=SYS_JTDO-SWO
PB4.Signal=GPIO_Input
PB5.Signal=GPIO_Input
PB6.Signal=GPIO_Input
PB7.Signal=GPIO_Input
PF0-OSC_IN.Signal=GPIO_Output
PF1-OSC_OUT.Signal=GPIO_Output

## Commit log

2026-03-01 KiCad .gitignore file
2026-03-01 Test project files
    [synthia.kicad_pcb, synthia.kicad_sch, synthia_test_subsheet.kicad_sch]
2026-03-01 Meaningful Commit Message (Test)
    [synthia.kicad_sch]
2026-03-01 This has the power part made out k
    [synthia.kicad_sch]
2026-03-15 Stuff from this meeting
    [synthia.kicad_sch]
2026-03-25 Ayo this is Anthony Bruno commiting to Synthia. I'm Synthing it!
    [synthia.kicad_pcb]
2026-03-26 updated with new symbols
    [synthia.kicad_sch]
2026-03-26 Symbols for Button and Op Amp
    [L78M05CV.step, TL1105BF160Q.step]
2026-03-26 Embedded DAC and Button Matrix into IC style subsheets (Not Documented
    [Button_Matrix_sch.kicad_sch, Synthia_DAC.kicad_sch, synthia.kicad_sch]
2026-03-26 small edit to the Button Matrix schematic
    [Button_Matrix_sch.kicad_sch]
2026-03-26 deleted old test file
    [synthia_test_subsheet.kicad_sch]
2026-03-29 Started on the PCB, button matrix is active
    [Button_Matrix_sch.kicad_sch, TLV272IP.step, synthia.kicad_pcb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]
2026-04-02 More PCB Updates for the Matrix
    [synthia.kicad_pcb]
2026-04-09 Output circuit has been made into a schematic
    [synthia.kicad_sch]
2026-04-16 More updates to the Schematic, implemented some of the ports that will be on the pcb
    [LD1117V33.step, MJ-63022B.step, PJ-007.step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]
2026-04-16 Made changes to the schematic to implement some ports
    [synthia.kicad_sch]
2026-04-18 More updates to the Schematic, ports and solder points added for external components and were wired up
    [Button_Matrix_sch.kicad_sch, Synthia_DAC.kicad_sch, synthia.kicad_sch]
2026-04-19 More updates to Schematic, added latching switch as a symbol and footprint
    [synthia.kicad_pcb, synthia.kicad_sch]
2026-04-19 More changes made during Jank. Made a symbol and footprint for the latching switch
    [synthia.kicad_pcb, synthia.kicad_sch]
2026-04-25 fix: duplicate file cleanup
    [main.c]
2026-04-25 Add Timer (TIM1)
2026-04-25 feat: chord button scanning implementation
2026-05-10 did some pcb work, initial wiring complete
    [synthia.kicad_pcb, synthia.kicad_sch]
2026-05-11 Continued on PCB design and wiring, cannot continue until design has been further completed
    [synthia.kicad_pcb]
2026-05-11 added all 3D models for the footprints into the pcb design, fixed some DRC errors
    [L78M05CV.step, LD1117V33.step, LQFP144_STM.step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]
2026-05-12 continued PCB Work, Power circuit is wired
    [Button_Matrix_sch.kicad_sch, synthia.kicad_pcb, synthia.kicad_sch]
2026-05-12 More PCB Work, Button Matrix fully routed and strumpad wiring done
    [synthia.kicad_pcb, synthia.kicad_sch]
2026-05-12 Again did more Work on the PCB, Battery terminal is wired
    [synthia.kicad_pcb, synthia.kicad_sch]
2026-05-13 Completely had to redesign most of the pins allocated for power and designed some of the ports that will save us from potentially bricking the stm. PCB wiring for the updated schematic is NOT DONE
    [1063.step, ATS08A-E_CTS.step, BAS70-05.STEP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]
2026-05-14 Updated schematic now routed on the PCB, everything should be prepped for next step
    [synthia.kicad_pcb]
2026-05-14 slight tweak, previous commit still applies\
    [synthia.kicad_pcb]
2026-05-14 Cosmetic changes to PCB made
    [synthia.kicad_pcb]
2026-05-15 Organized Font and Rhythm button matrices and associated switches. Not in their final location so power and IO is not routed for them yet
    [synthia.kicad_pcb, synthia.kicad_sch]
2026-05-15 Scaled down the PCB to be able to fit inside the 3 model case
    [synthia.kicad_pcb]
2026-05-16 made 3D model of current PCB, will likely be updated and replaced when needed
    [PCB-3D-model.step, synthia.kicad_pcb, synthia.kicad_sch]
2026-05-20 Power is pretty much fully routed, some data lines need to be routed. Final component locations established and confirmed by Jeremy and Ever.
    [PCB-3D-model-2.step, synthia.kicad_pcb]
2026-05-21 PCB Revision 1.0 complete, Ground zones are filled, all components are wired, and holes are made for standoffs for case installment. Final changes to the onshape will need to be made to accomodate th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
    [synthia.kicad_pcb, synthia.kicad_sch]
2026-05-21 PCB Revision 1.0 complete, Ground zones are filled, all components are wired, and holes are made for standoffs for case installment. Final changes to the onshape will need to be made to accomodate th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
    [synthia.kicad_sch]
2026-08-17 "what am I looking at" been too long - jeremy
    [Synthia-Firmware.ioc, main.c]
2026-09-04 Made slight efficiency improvements to wiring.
    [synthia.kicad_pcb]
2026-09-24 Added a few changes to the formatting of the PCB file, specifically for outputting the file and rendering as images
    [synthia.kicad_pcb]
2026-09-26 🧑‍💻 Create pull_request_template.md for improving pull requests
2026-10-11 Replace the .1 microfarad decoupling 0402 sized capacitors with identically rated 0603 capacitors. Refine design to adhere with design rules. Silkscreen is incomplete and will need to be edited to fi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
2026-10-31 Update PCB to align ports
2026-11-07 Overhauled the audio amplification system to be better suited using a proper Audio amplifier rather than just the Op Amp system. PCB Changes yet to be made. Changed Resistor values to 10K for better 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
2026-11-07 Rerouted traces to prevent different sized traces from being on the same wire. Still have work to do on the new components from previous commit
2026-11-08 implement new audio amplifier IC and update PCB for mechanical. 3D Model will be in the repo soon
2026-11-08 Finalized trace rerouting and did via stitching. Need to look over routing to confirm good design.
2026-11-09 refine routing on the audio conversion traces on the PCB, cleanup some silkscreen items that are not needed
